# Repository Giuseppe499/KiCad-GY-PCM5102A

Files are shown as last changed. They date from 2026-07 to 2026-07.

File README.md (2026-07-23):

# KiCad GY-PCM5102A

Open source recreation of the popular GY-PCM5102A I2S DAC module, built in KiCad.

## PCB renders
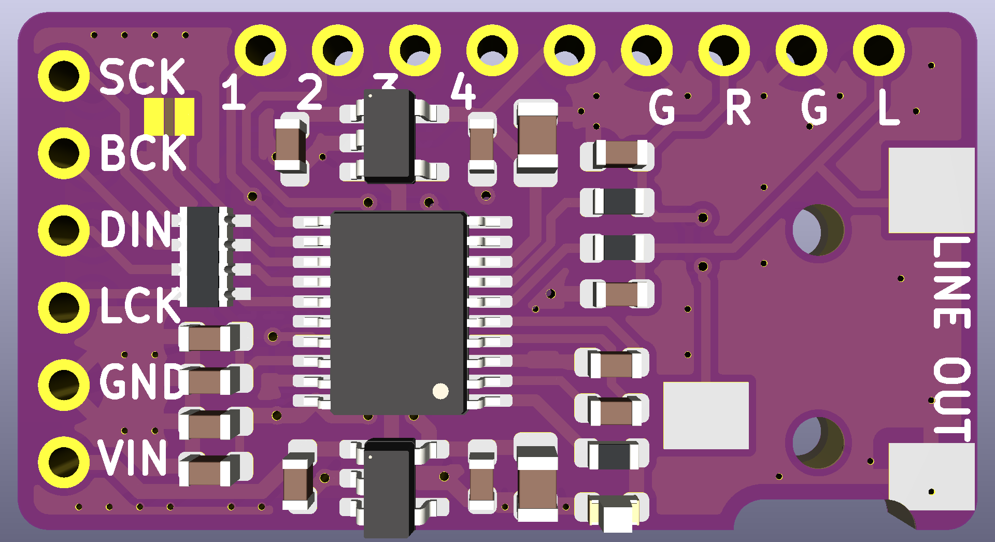
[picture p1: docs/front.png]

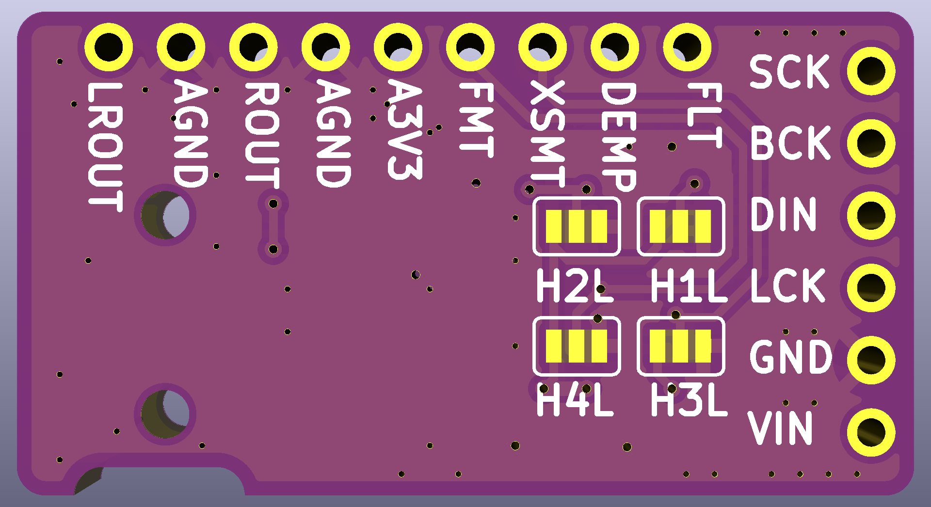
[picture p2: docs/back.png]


## Schematic
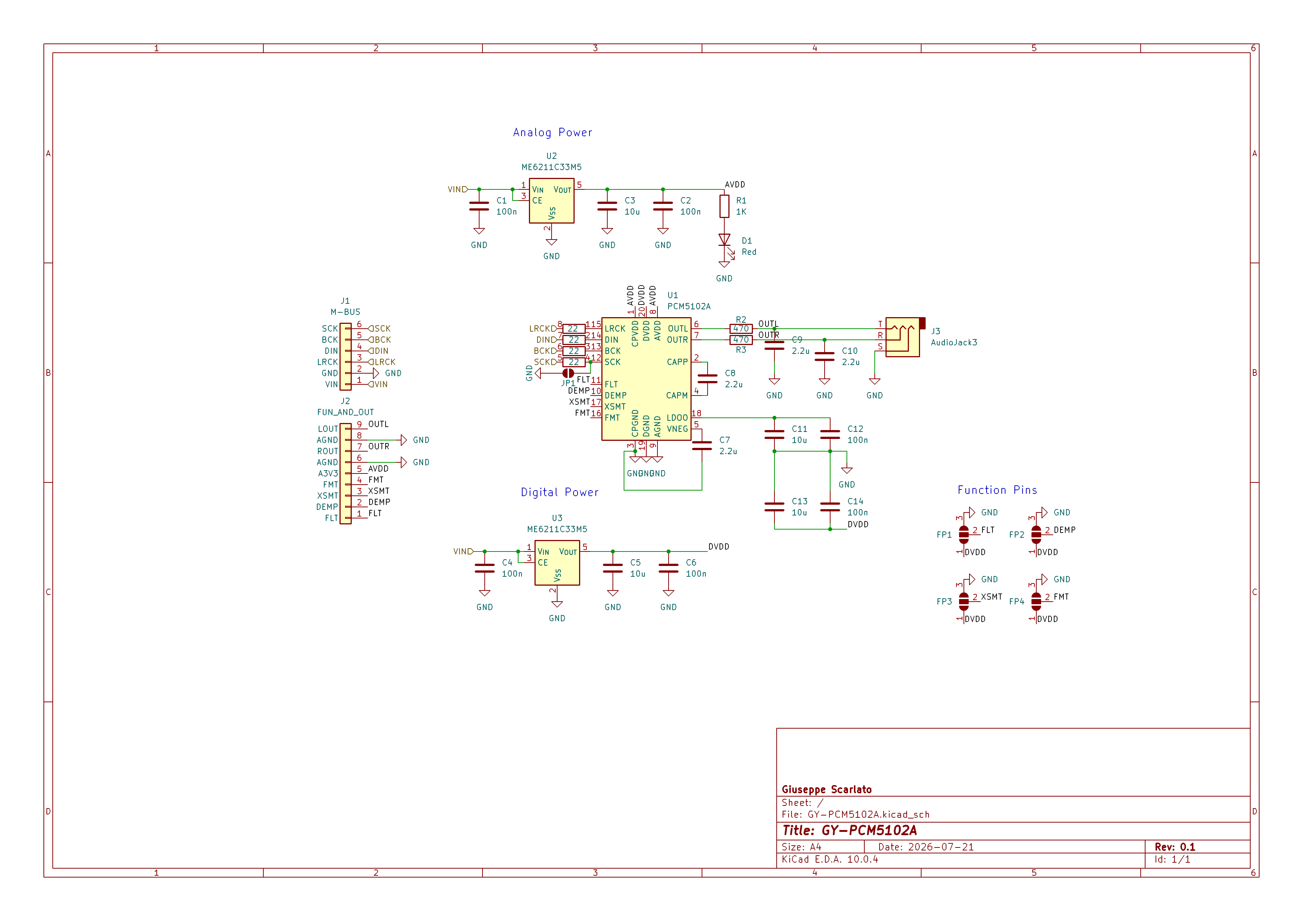
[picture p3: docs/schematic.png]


## License & Attribution

This project is an independent, open-source recreation based on the GY-PCM5102A modules.

Licensed under the [CERN Open Hardware Licence Version 2 - Strongly Reciprocal (CERN-OHL-S)](LICENSE).

Copyright (c) Giuseppe Scarlato 2026.

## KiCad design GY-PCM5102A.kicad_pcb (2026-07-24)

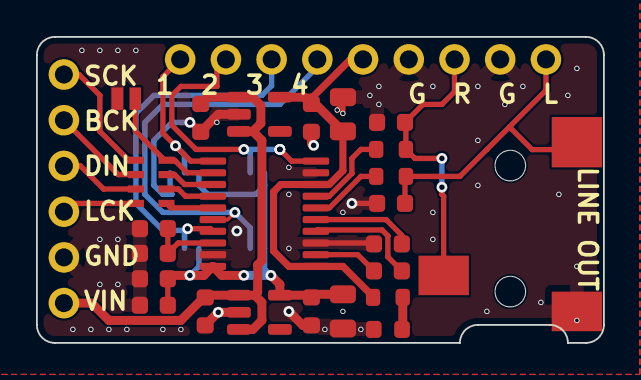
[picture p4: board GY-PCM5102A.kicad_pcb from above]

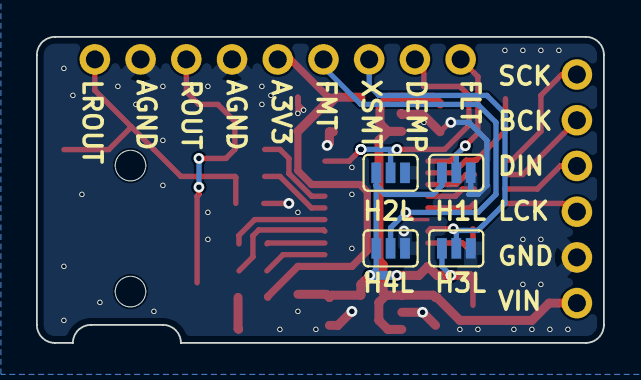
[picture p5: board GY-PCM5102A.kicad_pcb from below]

Board: 2 copper layers, 31.5 x 17.0 mm, 30 parts (4 on the bottom side), 25 nets.

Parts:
C1, C2, C4, C6, C12, C14: 100n; C_0603_1608Metric
C3, C5: 10u; C_0805_2012Metric
C7, C8, C9, C10: 2.2u; C_0603_1608Metric
C11, C13: 10u; C_0603_1608Metric
D1: Red; LED_0603_1608Metric
H1L, H2L, H3L, H4L: SolderJumper-3_P1.3mm_Open_Pad0.55x1.15mm
J1: M-BUS; PinHeader_1x06_P2.54mm_Vertical
J2: FUN_AND_OUT; PinHeader_1x09_P2.54mm_Vertical
J3: AudioJack3; Jack_3.5mm_CUI_SJ-3523-SMT_Horizontal
JP1: SolderJumper_2_Open; SolderJumper-2_P1.3mm_Open_Pad1.0x1.5mm
R1: 1K; R_0603_1608Metric
R2, R3: 470; R_0603_1608Metric
RN1: 22; R_Array_Concave_4x0603
U1: PCM5102A; TSSOP-20_4.4x6.5mm_P0.65mm
U2, U3: ME6211C33M5; SOT-23-5

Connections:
/AVDD: C2.1, C3.1, J2.5 (A3V3), R1.2, U1.1 (CPVDD), U1.8 (AVDD), U2.5 (V_{OUT})
/BCK: J1.5 (BCK), RN1.6 (R3.2)
/DEMP: H2L.2 (C), J2.2 (DEMP), U1.10 (DEMP)
/DIN: J1.4 (DIN), RN1.7 (R2.2)
/DVDD: C5.1, C6.1, C13.1, C14.2, H1L.1 (A), H2L.1 (A), H3L.1 (A), H4L.1 (A), U1.20 (DVDD), U3.5 (V_{OUT})
/FLT: H1L.2 (C), J2.1 (FLT), U1.11 (FLT)
/FMT: H4L.2 (C), J2.4 (FMT), U1.16 (FMT)
/LRCK: J1.3 (LRCK), RN1.8 (R1.2)
/OUTL: C9.1, J2.9 (LOUT), J3.T, R2.2
/OUTR: C10.1, J2.7 (ROUT), J3.R, R3.2
/SCK: J1.6 (SCK), RN1.5 (R4.2)
/VIN: C1.1, C4.1, J1.1 (VIN), U2.1 (V_{IN}), U2.3 (CE), U3.1 (V_{IN}), U3.3 (CE)
/XSMT: H3L.2 (C), J2.3 (XSMT), U1.17 (XSMT)
GND: C1.2, C2.2, C3.2, C4.2, C5.2, C6.2, C7.2, C9.2, C10.2, C11.2, C12.2, C13.2, C14.1, D1.1 (K), H1L.3 (B), H2L.3 (B), H3L.3 (B), H4L.3 (B), J1.2 (GND), J2.6 (AGND), J2.8 (AGND), J3.S, JP1.1 (A), U1.3 (CPGND), U1.9 (AGND), U1.19 (DGND), U2.2 (V_{SS}), U3.2 (V_{SS})
unnamed: D1.2 (A), R1.1
unnamed: JP1.2 (B), RN1.4 (R4.1), U1.12 (SCK)
unnamed: RN1.1 (R1.1), U1.15 (LRCK)
unnamed: RN1.2 (R2.1), U1.14 (DIN)
unnamed: RN1.3 (R3.1), U1.13 (BCK)
unnamed: C8.2, U1.4 (CAPM)
unnamed: C8.1, U1.2 (CAPP)
unnamed: C11.1, C12.1, U1.18 (LDOO)
unnamed: R2.1, U1.6 (OUTL)
unnamed: R3.1, U1.7 (OUTR)
unnamed: C7.1, U1.5 (VNEG)

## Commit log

2026-07-21 feat: add schematic and basic KiCad files
    [GY-PCM5102A.kicad_pcb, GY-PCM5102A.kicad_sch]
2026-07-23 feat: populate PCB and update schematic
    [GY-PCM5102A.kicad_pcb, GY-PCM5102A.kicad_sch]
2026-07-23 feat: Add silkscreen. Change PCB color to magenta in 3D viewer.
    [GY-PCM5102A.kicad_pcb]
2026-07-23 fix: AVDD via too close to capacitor ground
    [GY-PCM5102A.kicad_pcb]
2026-07-24 fix: missing H*L text for functions jumpers. Improve silkscreen positioning.
    [GY-PCM5102A.kicad_pcb]
